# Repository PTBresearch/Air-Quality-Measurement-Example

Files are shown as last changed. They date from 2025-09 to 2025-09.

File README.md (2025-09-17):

# Note: This repository is meant as an example. The code is incomplete and not the latest version. 

# Note: The global InfluxDB instance is planned to be replaced by Fiware.

# Air Quality

## Sensors List (Not Complete)

+ **PPD42NS** (Dust Concentration)

+ **BME280** (Humidity, Air Pressure, Temperature)

+ **CCS811** (TVOC Value, CO2 Equivalent)

+ **MAX31855PMB1#** (Temperature)

+ **SHT35** (Temperature, Humidity)

+ **GUVA-S12D** (UV)

+ **TCS34725** Light Sensor (RGB, Color Temperature, Brightness, Reference Value)

+ **MH-Z19C** (CO2 Value Infrared Sensor, Temperature)

+ **SPH** (DB)

+ **HP206C** ()

## Images and Render

<table>
  <tr>
    <td>
      Front Image
      <figcaption>Blender Case with PCB Render</figcaption>
    </td>
    <td>
      Front Image
      <figcaption>Blender Base with PCB Render</figcaption>
    </td>
    <td>
      Front Image
      <figcaption>Blender PCB Render</figcaption>
    </td>
  </tr>
  <tr>
    <td>
      Front Image
      <figcaption>Full Top</figcaption>
    </td>
    <td>
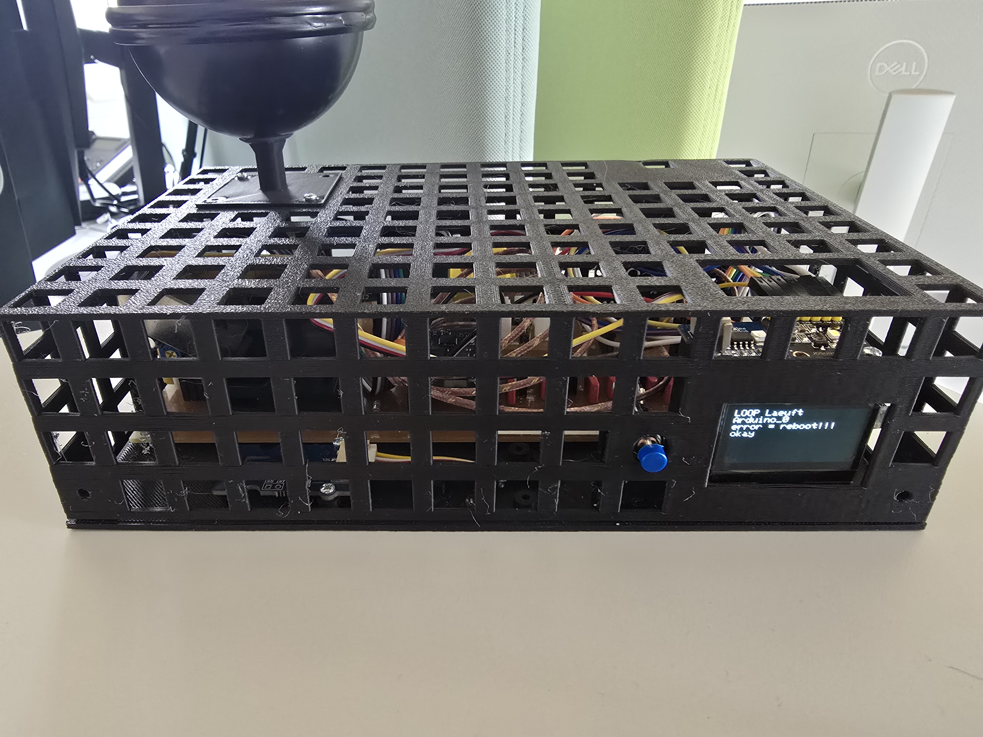
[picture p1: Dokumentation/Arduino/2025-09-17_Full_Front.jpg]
Front Image
      
      <figcaption>Full Front</figcaption>
    </td>
    <td>
      Front Image
      <figcaption>Sensor Station</figcaption>
    </td>
  </tr>
  <tr>
    <td>
      Side Image
      <figcaption>Open PCB V1</figcaption>
    </td>
    <td>
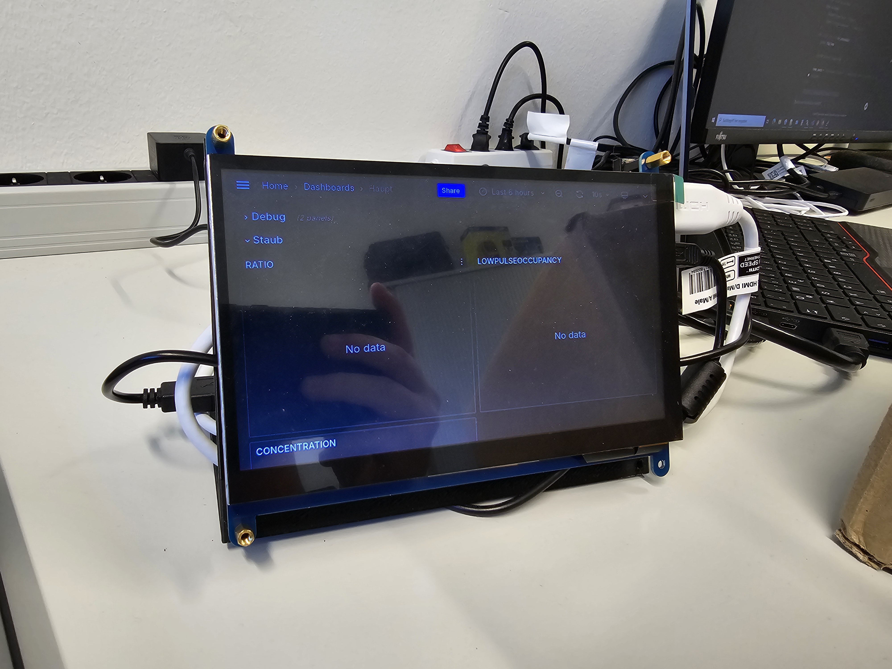
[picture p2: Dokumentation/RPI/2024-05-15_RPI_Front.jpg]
Front Image
      
      <figcaption>Front View</figcaption>
    </td>
    <td>
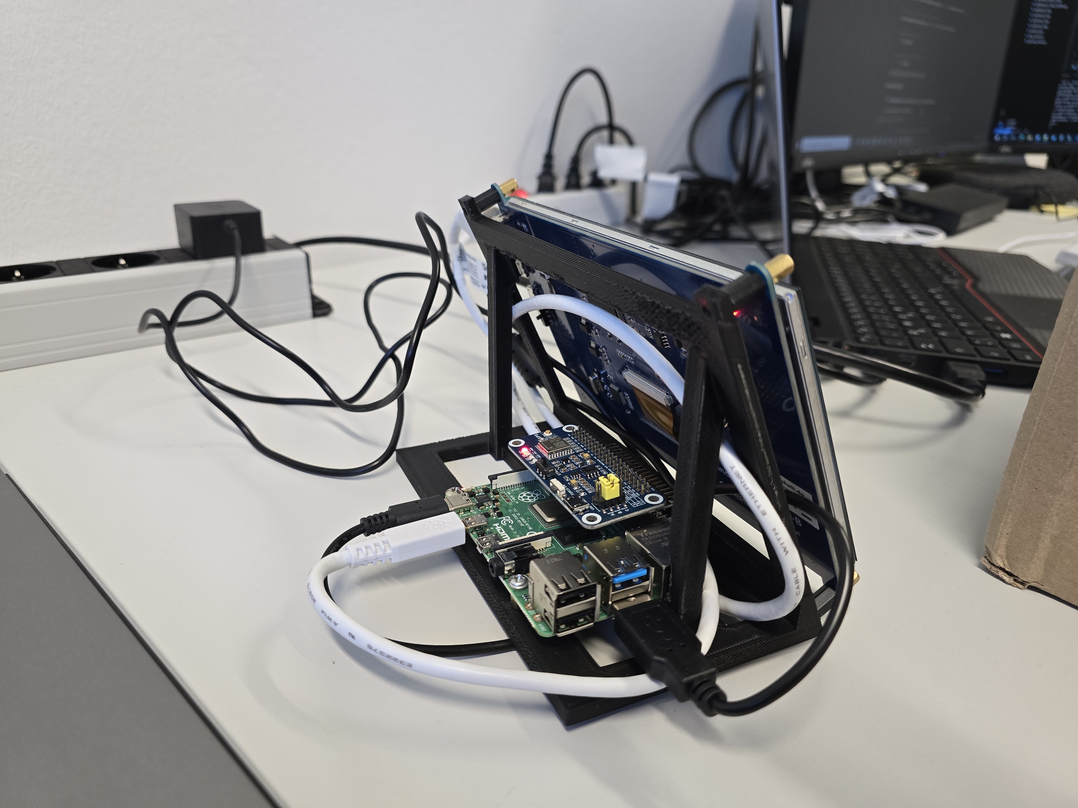
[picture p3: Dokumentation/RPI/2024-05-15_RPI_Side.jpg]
Side Image
      
      <figcaption>Side View</figcaption>
    </td>
  </tr>
</table>

## Structure

```
.
├── Arduino-Code/          # The main folder for all microcontroller code.
│   ├── Main/              # Code for the primary Arduino prototype (likely ESP8266).
│   │   ├── lib/           # Libraries for this specific project.
│   │   └── Main.ino # The main program file for the Arduino.
│
├── Dokumentation/         # Images.
│
├── Files/                 # Specific files relevant to hardware and measurements.
│   ├── Gehaeuse/          # 3D models and design files for the project's enclosure.
│   └── Platinen/          # Design files (Gerber files, etc.) for the printed circuit boards (PCBs).
│
└── Raspberry-Installer/   # Scripts and files for setting up the Raspberry Pi.
    └── Docker/            # Docker configurations and source code for installing services on the Pi.
        └── src/           # Source code used by the Docker containers.
```

## Function

```
┌── Raspberry Pi
│   └── Creates a Wi-Fi network
│
└── Arduino
    ├── Connects to the Wi-Fi network
    │
    ├── Reads data from the sensor
    │
    └── Sends data over Wi-Fi to the API
        │
        └── API
            ├── Collects the sent data
            │
            ├── Inserts the data into a local database (InfluxDB)
            │
            └── Inserts the data into a global database (InfluxDB)
```

## Example JSON-Structure

```
{
  "arduino_board": "<arduino_id>",
  "sensors": [
    {
      "name": "<sensor_name>",
      "sensor_model": "<sensor_model>",
      "readings": [
        {
          "type": "<influx measurement>",
          "value": VALUE,
          "unit": "<unit>"
          "label": "<label optional>"
        },
        {
          "type": "<influx measurement>",
          "value": VALUE,
          "unit": "<unit>"
          "label": "<label optional>"
        }
      ]
    },
    {
      "name": "bme280",
      "sensor_model": "",
      "readings": [
        {
          "type": "temperature",
          "value": VALUE,
          "unit": "celsius"
        },
        {
          "type": "pressure",
          "value": VALUE,
          "unit": "hpa"
        },
        {
          "type": "humidity",
          "value": VALUE,
          "unit": "%"
        }
      ]
    }
  ]
}
```

---

## Instalation

1. Download: 

```bash
git clone <url> luftqualitaet
```

2. Edit ```WLAN_SSID``` in ```luftqualitaet/Raspberry-Installer/config.sh``` 
```bash
export replace=<Hostname>
sed -i -e 's/WLAN_SSID = Hostname/WLAN_SSID = ${replace}/g' luftqualitaet/Raspberry-Installer/config.sh
```

3. (Optional) Set Proxy Settings ```luftqualitaet/Raspberry-Installer/Docker/.env```
```bash
echo "http_proxy=http://webproxy:8080
https_proxy=http://webproxy:8080
no_proxy=influx,localhost" > /home/pi/luftqualitaet/Raspberry-Installer/Docker/.env
```

4. Login as Root
```bash
sudo -i
```

5. Change directory to Installer Location
```bash
cd /home/pi/luftqualitaet/Raspberry-Installer
```

6. Make Script executeable
```bash
chmod +x config.sh setup.sh
```

7. Set Current Time
```bash
HTTP_DATE=$(curl -x http://webproxy:8080  -ksI 'https://ptb.de' | grep -i '^date:' | sed 's/Date: //i' | sed 's/ (GMT)//')
if [ -n "$HTTP_DATE" ]; then date -s "$HTTP_DATE" && echo "Systemzeit erfolgreich gesetzt."; else echo "WARNUNG: Konnte die Zeit nicht über HTTP abrufen."; fi
```

8. Run Script
```
./setup.sh
```

9. Change directory to Docker Location
```bash
cd /home/pi/luftqualitaet/Raspberry-Installer/Docker
```

10. Start Docker
```bash
docker compose up -d
```

11. Setup Influxdb (http://hostname:8086) and Grafan (http://hostname:3000) 

12. Set InfluxDB Token in Config ```/home/pi/Raspberry-Installer/Docker/src/config.yml````

13. Restart Docker
```bash
docker compose down
docker compose up -d
```

14. Restart Raspberry PI
```bash
systemctl reboot
```

---

## Components

### Raspberry PI

| Component | Order Link | Datasheet Link(s) | Further Information |
|---|---|---|---|
| Pi 4B | [https://www.reichelt.de/das-reichelt-raspberry-pi-4-b-4-gb-all-in-bundle-rpi-4b-4gb-allin-p263086.html](https://www.reichelt.de/das-reichelt-raspberry-pi-4-b-4-gb-all-in-bundle-rpi-4b-4gb-allin-p263086.html) | | |
| Micro SD | [https://www.reichelt.de/de/de/shop/produkt/microsdxc-speicherkarte_128gb_samsung_pro_plus-313955](https://www.reichelt.de/de/de/shop/produkt/microsdxc-speicherkarte_128gb_samsung_pro_plus-313955) | | |
| GPS | [https://www.reichelt.de/de/de/shop/produkt/raspberry_pi_shield_-_multi-gnss_l76x-266060](https://www.reichelt.de/de/de/shop/produkt/raspberry_pi_shield_-_multi-gnss_l76x-266060) | | |
| Raspberry Pi Shield | [https://www.reichelt.de/de/de/shop/produkt/raspberry_pi_shield_-_display_lcd-touch_7_800x480_pixel-282508](https://www.reichelt.de/de/de/shop/produkt/raspberry_pi_shield_-_display_lcd-touch_7_800x480_pixel-282508) | | |

### Sensor Station

| Component | Sensor Type | Order Link | Datasheet Link(s) | Notes | Ambient Temperature | Humidity | Air Pressure |
|---|---|---|---|---|---|---|---|
| **BME280** | Temp & Pressure Sensor | [https://www.reichelt.de/ch/de/shop/produkt/entwicklerboards\_-\_temperatur-\_feuchtigkeits-*und\_drucksensor*-253982](https://www.reichelt.de/ch/de/shop/produkt/entwicklerboards_-_temperatur-_feuchtigkeits-_und_drucksensor_-253982) | [https://cdn-reichelt.de/documents/datenblatt/A300/BST-BME280-DS002-1509607.pdf](https://cdn-reichelt.de/documents/datenblatt/A300/BST-BME280-DS002-1509607.pdf) | Inaccurate temperature (error tolerance of +3°C) | Accuracy: +1.0°C \<br\> Range: -40°C to +85°C \<br\> Max Deviation: Up to +1.5°C | Accuracy: +3% rF \<br\> Range: 0% to 100% rF \<br\> Max Deviation: up to +5% | Accuracy: +1 hPa \<br\> Range: 300 hPa \<br\> Max Deviation: Up to +1.7 hPa |
| **CCS811** | TVOC | [https://www.reichelt.de/ch/de/shop/produkt/entwicklerboards\_-\_sensor\_fuer\_luftqualitaet\_ccs811-253655](https://www.reichelt.de/ch/de/shop/produkt/entwicklerboards_-_sensor_fuer_luftqualitaet_ccs811-253655) | [https://cdn-reichelt.de/documents/datenblatt/A300/SEN-CCS811V1-DATENBLATT-02-11-2020.pdf](https://cdn-reichelt.de/documents/datenblatt/A300/SEN-CCS811V1-DATENBLATT-02-11-2020.pdf) | Has a burn-in period (48 hours) and a warm-up time (20 min) before it becomes accurate | Accuracy: +3°C \<br\> Range: 0°C to +50°C \<br\> Max Deviation: approx. +5°C | Range: 10% to 95% | |
| **PPD42NS** | Dust | [https://www.reichelt.de/ch/de/shop/produkt/arduino\_-\_staubsensor\_ppd42ns-191264](https://www.reichelt.de/ch/de/shop/produkt/arduino_-_staubsensor_ppd42ns-191264) | [https://cdn-reichelt.de/documents/datenblatt/A300/101020012\_01.pdf](https://cdn-reichelt.de/documents/datenblatt/A300/101020012_01.pdf) | Must be straight, requires 3 min to warm up, arbitrary operation can lead to damage, standard settings should not be changed | Recommended Range: -10°C to +65°C | Range: 0% to 70% | |
| **MAX31855PMB1\#** | Typk Temp | [https://de.farnell.com/analog-devices/max31855pmb1/peripheriemodul-thermoel-digit/dp/2530496](https://de.farnell.com/analog-devices/max31855pmb1/peripheriemodul-thermoel-digit/dp/2530496) | [https://www.farnell.com/datasheets/2025616.pdf](https://www.farnell.com/datasheets/2025616.pdf) | Inaccurate temperature (error tolerance of +2°C) | Recommended Range: -20°C to +85°C | Range: 0% to 95% | |
| **D1 Mini** | D1 Mini | [https://www.reichelt.de/de/de/shop/produkt/d1\_mini\_-\_kompatibles\_esp8266\_board\_v2\_0-253978](https://www.reichelt.de/de/de/shop/produkt/d1_mini_-_kompatibles_esp8266_board_v2_0-253978) | | | | | |
| **D1 Mini** | D1 Mini Pro | https:www.reichelt.de/de/de/shop/produkt/d1\_mini\_pro\_-\_kompatibles\_esp8266\_board\_cp2104-266066 | | | | | |
| **Power Supply** | Breadboard | [https://www.reichelt.de/de/de/shop/produkt/entwicklerboards\_-\_spannungsversorgung\_f\_steckboards-202832](https://www.reichelt.de/de/de/shop/produkt/entwicklerboards_-_spannungsversorgung_f_steckboards-202832) | [https://cdn-reichelt.de/documents/datenblatt/A300/DATENBLATTSBC-POW-BB.pdf](https://cdn-reichelt.de/documents/datenblatt/A300/DATENBLATTSBC-POW-BB.pdf) | Too high voltage can damage the device or even lead to a fire | Recommended Range: 0°C to +70°C | Range: 10% to 60% (Absolutely not intended for humid rooms) | |
| **GSM18E09-P1J** | Plug-in Power Supply | [https://www.conrad.de/de/p/mean-well-gsm18e09-p1j-steckernetzteil-festspannung-9-v-dc-2-a-18-w-1837961.html](https://www.conrad.de/de/p/mean-well-gsm18e09-p1j-steckernetzteil-festspannung-9-v-dc-2-a-18-w-1837961.html) | [https://asset.conrad.com/media10/add/160267/c1/-/en/001837961DS01/datenblatt-1837961-mean-well-gsm18e09-p1j-steckernetzteil-festspannung-9-vdc-2-a-18-w.pdf](https://asset.conrad.com/media10/add/160267/c1/-/en/001837961DS01/datenblatt-1837961-mean-well-gsm18e09-p1j-steckernetzteil-festspannung-9-vdc-2-a-18-w.pdf) | Only lasts 3 years and is only 88% efficient | Recommended Range: -25 to +60 | Range: 20% to 90% | |
| **SHT35** | Temp & Humidity | [https://de.farnell.com/seeed-studio/101020212/sensorplatine-arduino-board/dp/3932104](https://de.farnell.com/seeed-studio/101020212/sensorplatine-arduino-board/dp/3932104) | [https://www.farnell.com/datasheets/3708357.pdf](https://www.farnell.com/datasheets/3708357.pdf) | Environmentally sensitive and should not be touched with fingers as it can be damaged | Recommended Range: -40°C to 125°C | Range: 10% to 90% | |
| **ADC** | Analog Digital Converter | [https://www.conrad.de/de/p/joy-it-ky053adc-raspberry-pi-erweiterungs-platine-passend-fuer-einplatinen-computer-raspberry-pi-raspberry-pi-a-b-1656368.html](https://www.conrad.de/de/p/joy-it-ky053adc-raspberry-pi-erweiterungs-platine-passend-fuer-einplatinen-computer-raspberry-pi-raspberry-pi-a-b-1656368.html) | [https://asset.conrad.com/media10/add/160267/c1/-/de/001656368DS01/datenblatt-1656368-joy-it-ky053adc-raspberry-pi-erweiterungs-platine-passend-fuer-einplatinen-compu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](https://asset.conrad.com/media10/add/160267/c1/-/de/001656368DS01/datenblatt-1656368-joy-it-ky053adc-raspberry-pi-erweiterungs-platine-passend-fuer-einplatinen-compu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) | Sensitive to interference due to its high resolution, which can make it slower to measure rapidly changing signals or values | Recommended Range: -40°C to 125°C | Range: 0% to 95% | |
| **GUVA-S12D** | UV Sensor | [https://www.reichelt.de/de/de/shop/produkt/arduino\_-\_uv-sensor\_guva-s12d-191215](https://www.reichelt.de/de/de/shop/produkt/arduino_-_uv-sensor_guva-s12d-191215) | [https://cdn-reichelt.de/documents/datenblatt/A300/101020043\_01.pdf](https://cdn-reichelt.de/documents/datenblatt/A300/101020043_01.pdf) | Can be altered by temperature, sensitive to environmental influences, not precise | Recommended Range: -30°C to +85°C | Range: 0% to 95% | |
| **TCS34725** | Light Sensor | [https://www.conrad.de/de/p/az-delivery-tcs34725-rgb-farb-sensor-mit-infrarot-filter-diy-modul-zur-farb-erkennung-kompatibel-mit-arduino-850037694.html](https://www.conrad.de/de/p/az-delivery-tcs34725-rgb-farb-sensor-mit-infrarot-filter-diy-modul-zur-farb-erkennung-kompatibel-mit-arduino-850037694.html) | [https://ams-osram.com/products/sensor-solutions/ambient-light-color-spectral-proximity-sensors/ams-tcs34725-color-sensor](https://ams-osram.com/products/sensor-solutions/ambient-light-color-spectral-proximity-sensors/ams-tcs34725-color-sensor) | Light can change measurement values, the sensor has a certain amount of background noise | Recommended Range: -40°C to +85°C | Range: 0% to 60% | |
| **MH-Z19C** | CO2 Sensor | [https://www.reichelt.de/de/de/shop/produkt/infrarot\_co2-sensor\_mh-z19c\_pinleiste\_rm\_2\_54-297320](https://www.reichelt.de/de/de/shop/produkt/infrarot_co2-sensor_mh-z19c_pinleiste_rm_2_54-297320) | [https://cdn-reichelt.de/documents/datenblatt/C150/MH-Z19CDATENBLATT.pdf](https://cdn-reichelt.de/documents/datenblatt/C150/MH-Z19CDATENBLATT.pdf) | Only works at optimal temperatures (-10 \~ 50 °C) and is sensitive to heat and sun | Recommended Range: -10°C to 50°C | Range: 0% to 95% | |
| **Teensy4.1** | Teensy4.1 | [https://www.reichelt.de/de/de/shop/produkt/teensy\_4\_1\_usb\_ohne\_header-283580](https://www.reichelt.de/de/de/shop/produkt/teensy_4_1_usb_ohne_header-283580) | [https://cdn-reichelt.de/documents/datenblatt/A300/TEENSY\_41\_DE.pdf](https://cdn-reichelt.de/documents/datenblatt/A300/TEENSY_41_DE.pdf) | Consumes a lot of power, lacks a Wi-Fi or Bluetooth connection, and can overheat during complex tasks | Recommended Range: -40°C to +85°C | Range: 0% to 95% | |
| **HP206C** | Grove - Barometer | [https://de.farnell.com/seeed-studio/101020068/sensor-barometer-arduino-raspberry/dp/4007687](https://de.farnell.com/seeed-studio/101020068/sensor-barometer-arduino-raspberry/dp/4007687) | [https://www.farnell.com/datasheets/3759062.pdf](https://www.farnell.com/datasheets/3759062.pdf) | The chip only accepts an input voltage of 1.8 V to 3.6 V. | Recommended Range: -40°C to +85°C | Range: 5% to 90% | |

### Mic

| Component | Sensor Type | Order Link | Datasheet Link(s) | Notes | Ambient Temperature | Humidity | Air Pressure |
|---|---|---|---|---|---|---|---|
| SPH0645 | Mems Mic | [https://www.reichelt.de/de/de/shop/produkt/entwicklerboards_-_mikrofone_sph0645-271874](https://www.reichelt.de/de/de/shop/produkt/entwicklerboards_-_mikrofone_sph0645-271874) | [https://cdn-reichelt.de/documents/datenblatt/A300/DEBO_MEMS_MIC_DB_EN.pdf](https://cdn-reichelt.de/documents/datenblatt/A300/DEBO_MEMS_MIC_DB_EN.pdf) | Sensitive to air, especially at the porthole (may require further investigation later) | Recommended Range: -40°C to +85°C | Range: 5% to 95% | |
| D1 Mini | D1 Mini | [https://www.reichelt.de/de/de/shop/produkt/d1_mini_-_kompatibles_esp8266_board_v2_0-253978](https://www.reichelt.de/de/de/shop/produkt/d1_mini_-_kompatibles_esp8266_board_v2_0-253978) | | | | | |
| D1 Mini | D1 Mini Pro | https:www.reichelt.de/de/de/shop/produkt/d1_mini_pro_-_kompatibles_esp8266_board_cp2104-266066 | | | | | |
| D1 Mini | D1 Mini Lite | [https://www.reichelt.de/de/de/shop/produkt/d1_mini_lite_-_kompatibles_esp8285_board-291438](https://www.reichelt.de/de/de/shop/produkt/d1_mini_lite_-_kompatibles_esp8285_board-291438) | | | | | |
| Teensy4.1 | Teensy4.1 | [https://www.reichelt.de/de/de/shop/produkt/teensy_4_1_usb_ohne_header-283580](https://www.reichelt.de/de/de/shop/produkt/teensy_4_1_usb_ohne_header-283580) | [https://cdn-reichelt.de/documents/datenblatt/A300/TEENSY_41_DE.pdf](https://cdn-reichelt.de/documents/datenblatt/A300/TEENSY_41_DE.pdf) | Consumes a lot of power, lacks a Wi-Fi or Bluetooth connection, and can overheat during complex tasks | Recommended Range: -40°C to +85°C | Range: 0% to 95% | |
| Power Supply | USB Charger | [https://www.reichelt.de/de/de/shop/produkt/usb-ladegeraet_5_v_1_a_usb-c_schwarz-268087?PROVID=2788](https://www.reichelt.de/de/de/shop/produkt/usb-ladegeraet_5_v_1_a_usb-c_schwarz-268087?PROVID=2788) | | | | | |

---

## Notes on Individual Sensors (Regarding Placement)

+ **BME280 Temperature, Air Pressure, Humidity Sensor:**
    + [https://www.makershop.de/download/bst-bme280-ds002.pdf](https://www.makershop.de/download/bst-bme280-ds002.pdf)
    + Do not place near heaters.

+ **CCS811 Carbon Dioxide Gas Sensor Metal Oxide:**
    + [https://www.makershop.de/download/CCS811_Datasheet-DS000459.pdf](https://www.makershop.de/download/CCS811_Datasheet-DS000459.pdf)
    + No special measures required.

+ **TCS3472 Color Sensor:**
    + [https://cdn.shopify.com/s/files/1/1509/1638/files/TCS3472_datasheet_1692bf77-3213-4bd2-9a66-8a9e70545e7e.pdf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](https://cdn.shopify.com/s/files/1/1509/1638/files/TCS3472_datasheet_1692bf77-3213-4bd2-9a66-8a9e70545e7e.pdf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)
    + The sensor should have access to light.
    + Not next to an LED on the ESP microcontroller.

+ **GRV Loudness Sensor:**
    + [https://cdn-reichelt.de/documents/datenblatt/A300/101020063_01.pdf](https://cdn-reichelt.de/documents/datenblatt/A300/101020063_01.pdf)
    + The sensor should have external access.
    + Should be able to capture ambient sound.
    + Do not place it behind a cover.

+ **GRV Dust Sensor:**
    + [https://cdn-reichelt.de/documents/datenblatt/A300/101020012_01.pdf](https://cdn-reichelt.de/documents/datenblatt/A300/101020012_01.pdf)
    + The chip on the back gets hot occasionally.
    + Has a built-in fan, so do not place it directly next to the GRV Loudness sensor.

---

## General Notes

+ The enclosure must be sufficiently open to allow air to flow in for measurements.
+ Ensure thermal, optical, and acoustic decoupling of the microcontroller from the sensors (use a partition).
+ Leave space for 2-3 additional sensors (check sensor dimensions with a reference image).
+ Leave space for 2 more ESPs (D1 Mini Lite), for a total of 3.

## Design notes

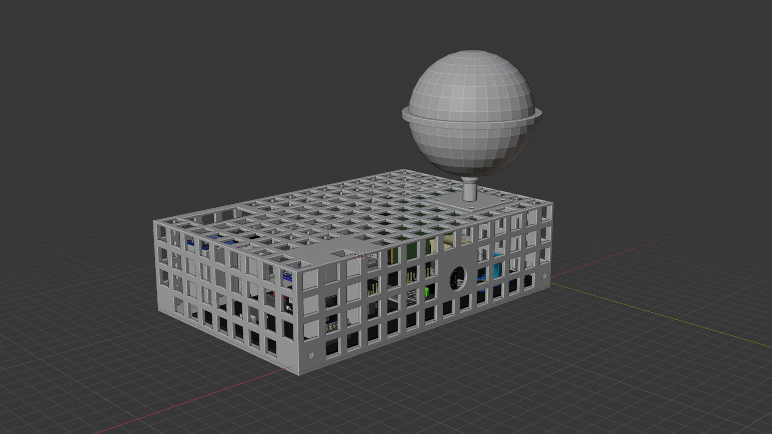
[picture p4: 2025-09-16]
Dokumentation/Arduino/2025-09-16-PCB-V3-Blender-Render-Case.png

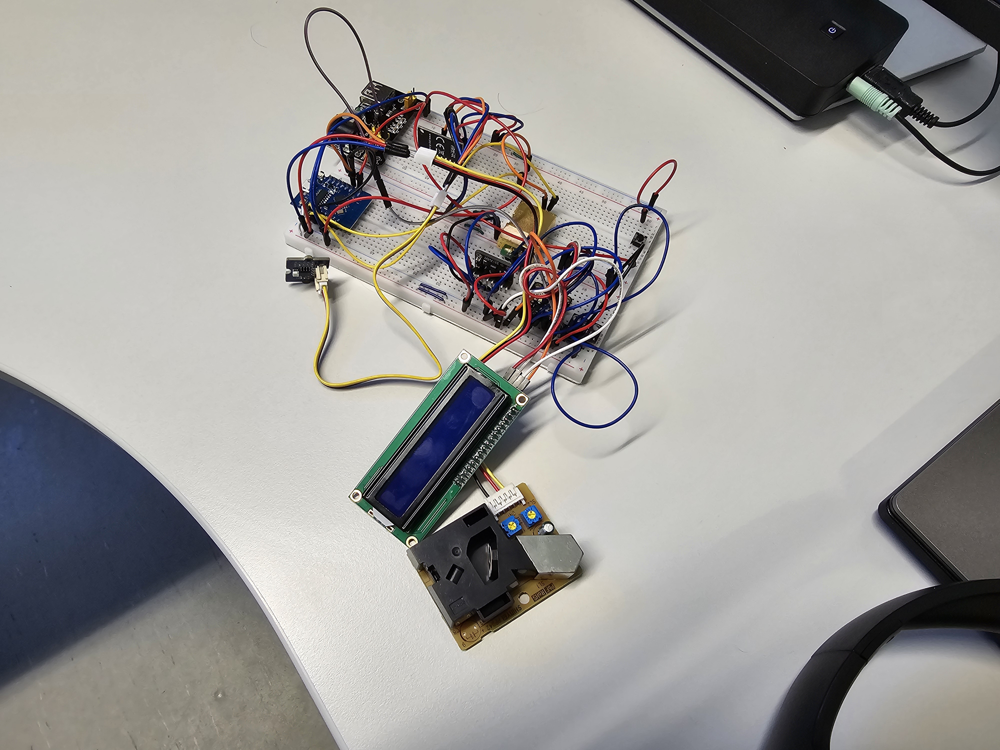
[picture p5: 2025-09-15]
Dokumentation/Arduino/2024-05-15_Breadboard_V2_Other_angle.jpg

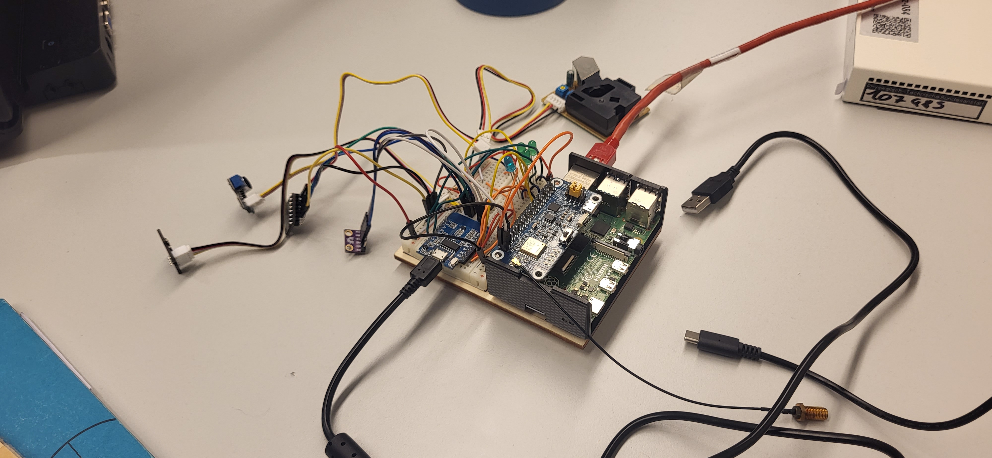
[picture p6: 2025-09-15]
Dokumentation/Arduino/2023-11-20_Breadboard_V1_Left.jpg

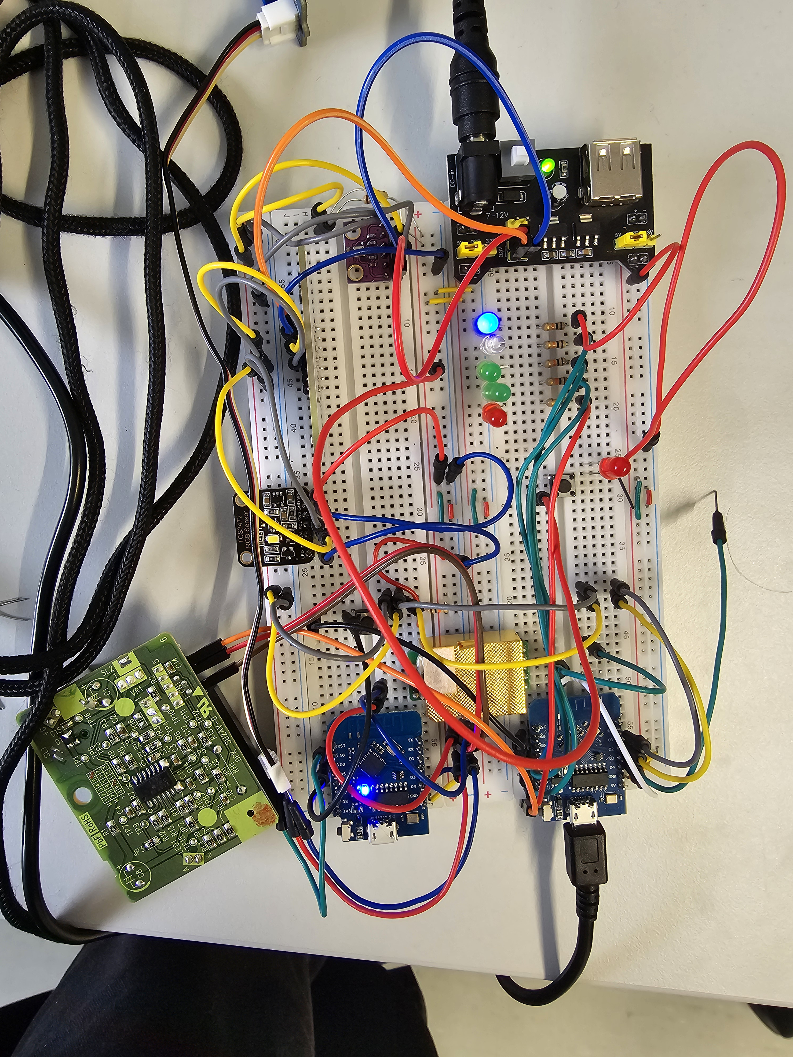
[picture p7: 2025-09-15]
Dokumentation/Arduino/2024-03-13_Breadboard_V2_Top.jpg

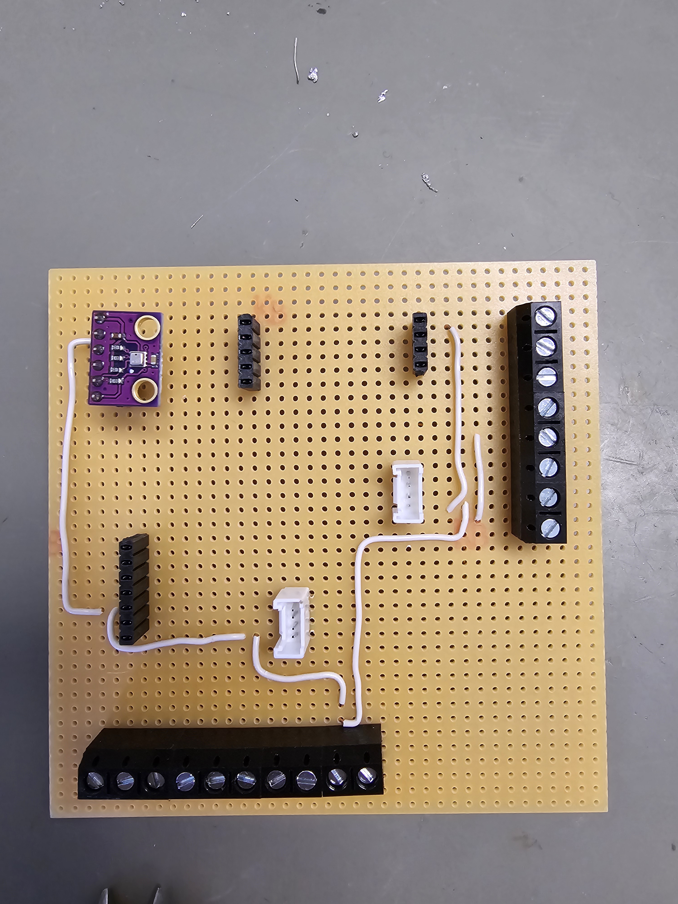
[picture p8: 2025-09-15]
Dokumentation/Arduino/2024-04-04_Circut_Board_Idea_Connectors.jpg

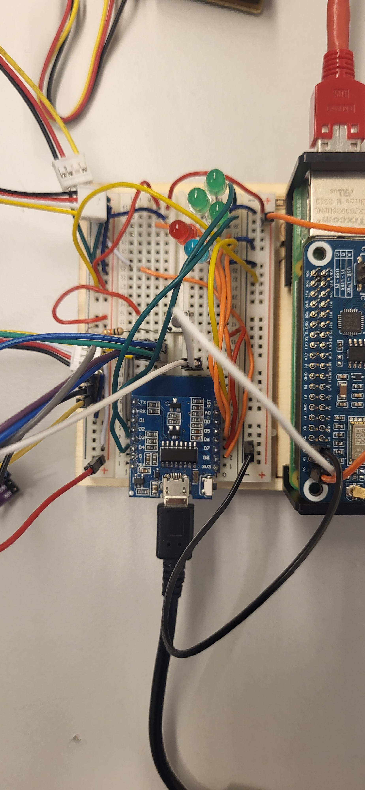
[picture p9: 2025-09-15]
Dokumentation/Arduino/2023-11-20_Breadboard_V1_Top.jpg

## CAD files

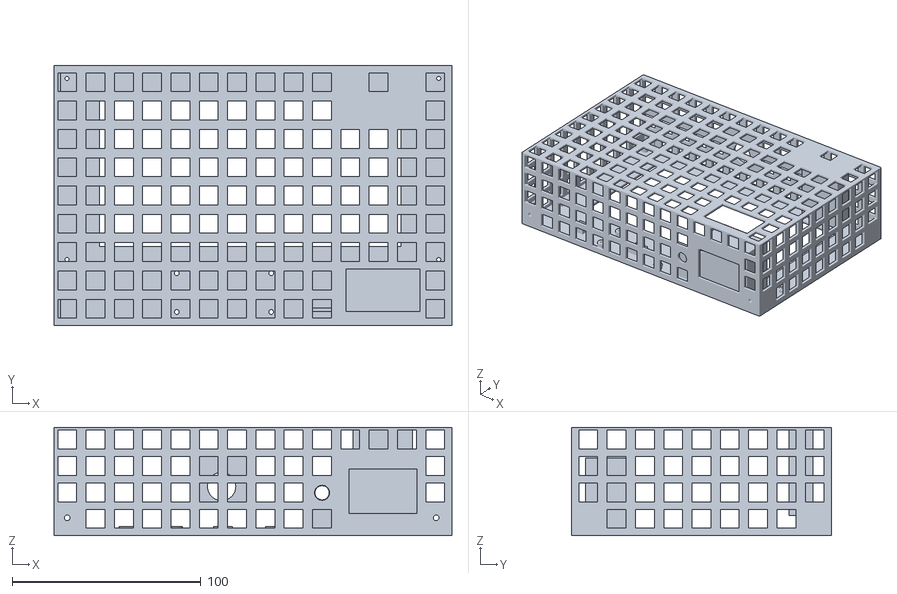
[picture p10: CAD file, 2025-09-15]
Files/Gehaeuse/Gehäuse.stl
210.9 x 138.0 x 57.5

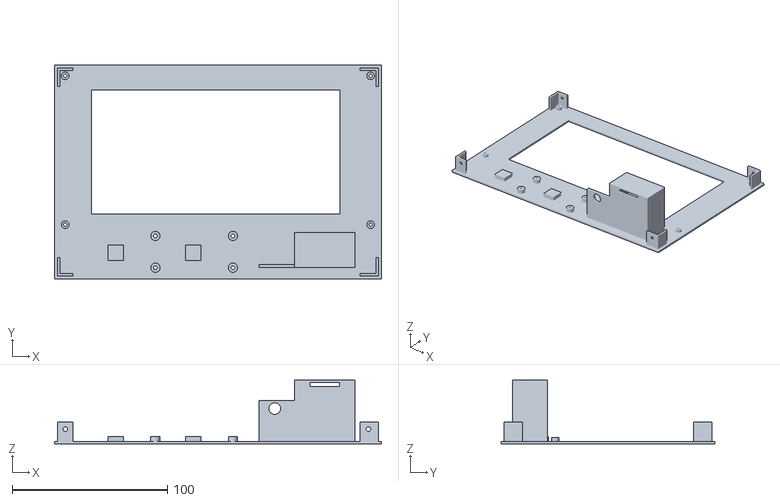
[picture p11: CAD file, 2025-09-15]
Files/Gehaeuse/Gehäuse-Boden.stl
210.9 x 138.0 x 41.1

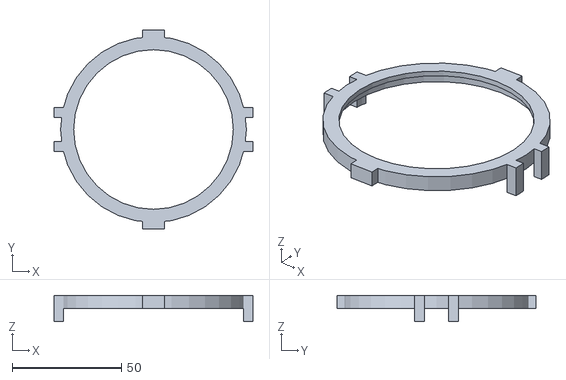
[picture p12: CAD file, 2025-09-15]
Files/Gehaeuse/Kugel-Halter.stl
91.0 x 91.0 x 12.0

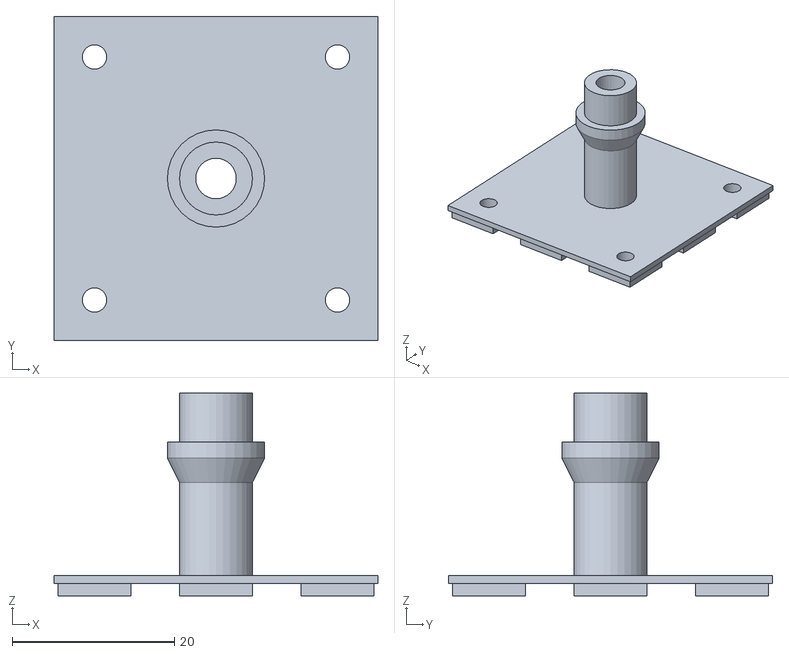
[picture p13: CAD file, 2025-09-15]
Files/Gehaeuse/Gehäuse-Globe.stl
40.0 x 40.0 x 25.0

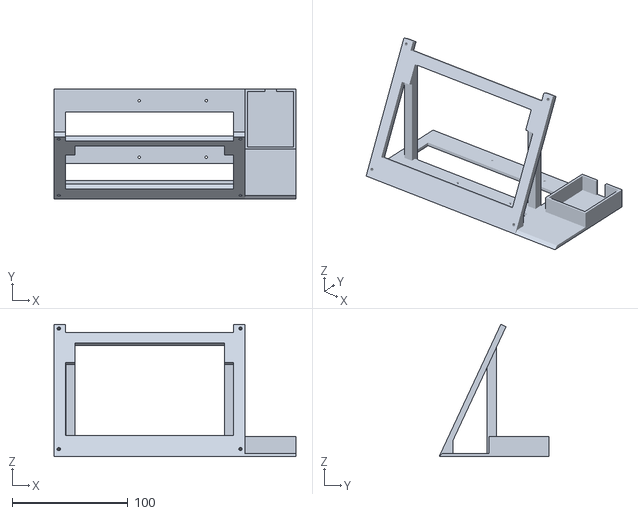
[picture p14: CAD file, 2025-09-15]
Files/Gehaeuse/Bildschirm.stl
209.1 x 95.0 x 114.5

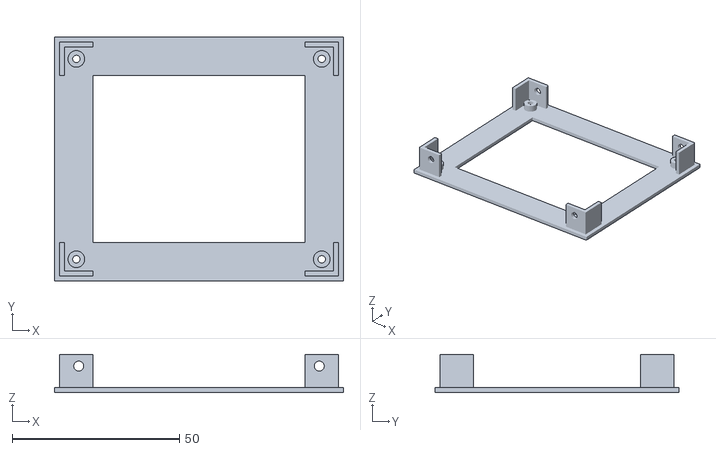
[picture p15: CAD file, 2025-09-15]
Files/Gehaeuse/Mikrofon-Boden.stl
86.5 x 73.0 x 11.5

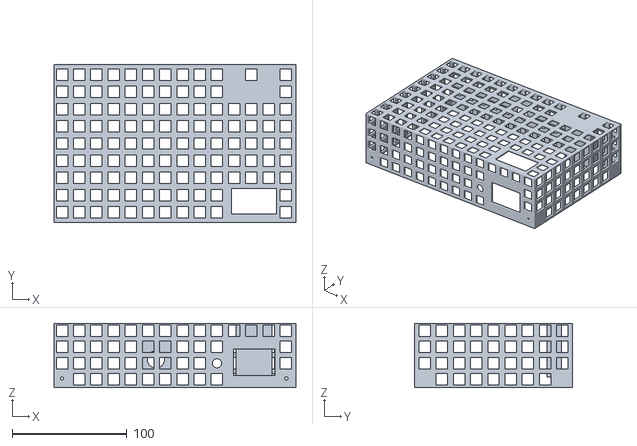
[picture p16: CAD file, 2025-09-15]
Files/Gehaeuse/Gehäuse-Deckel.stl
210.9 x 138.0 x 55.9

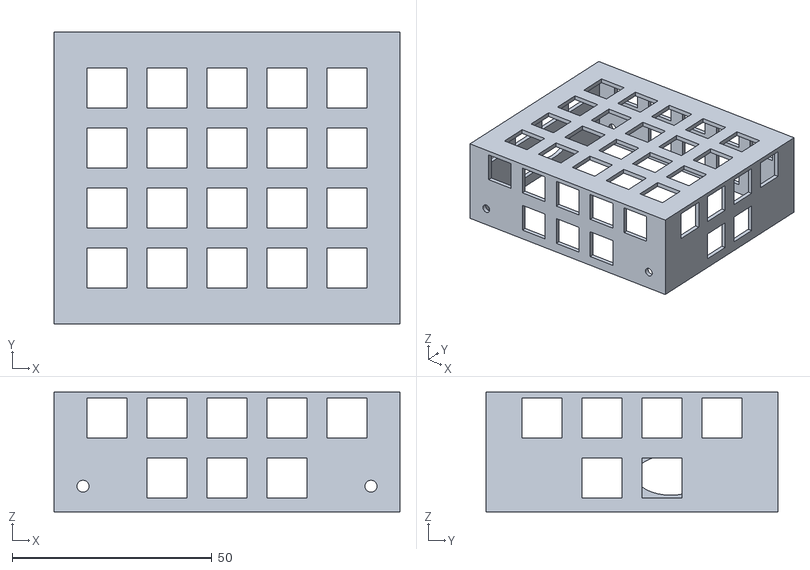
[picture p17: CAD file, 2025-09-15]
Files/Gehaeuse/Mikrofon-Deckel.stl
86.5 x 73.0 x 30.0

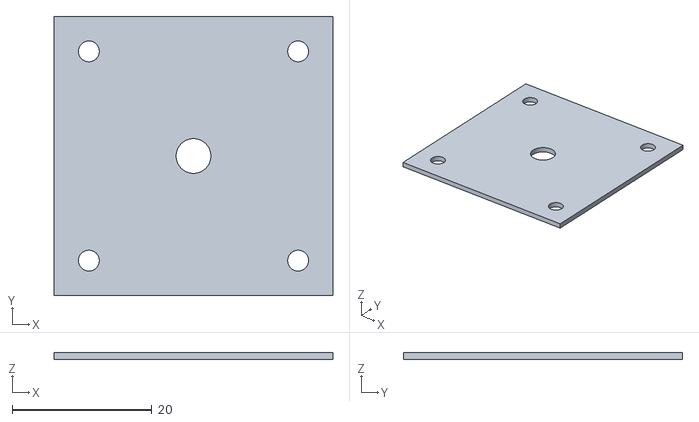
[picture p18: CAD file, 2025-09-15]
Files/Gehaeuse/Gehäuse-Globe-Boden.stl
40.0 x 40.0 x 1.00

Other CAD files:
Files/Gehaeuse/Bildschirm.blend
Files/Gehaeuse/Gehäuse.blend
Files/Gehaeuse/Mikrofon.blend

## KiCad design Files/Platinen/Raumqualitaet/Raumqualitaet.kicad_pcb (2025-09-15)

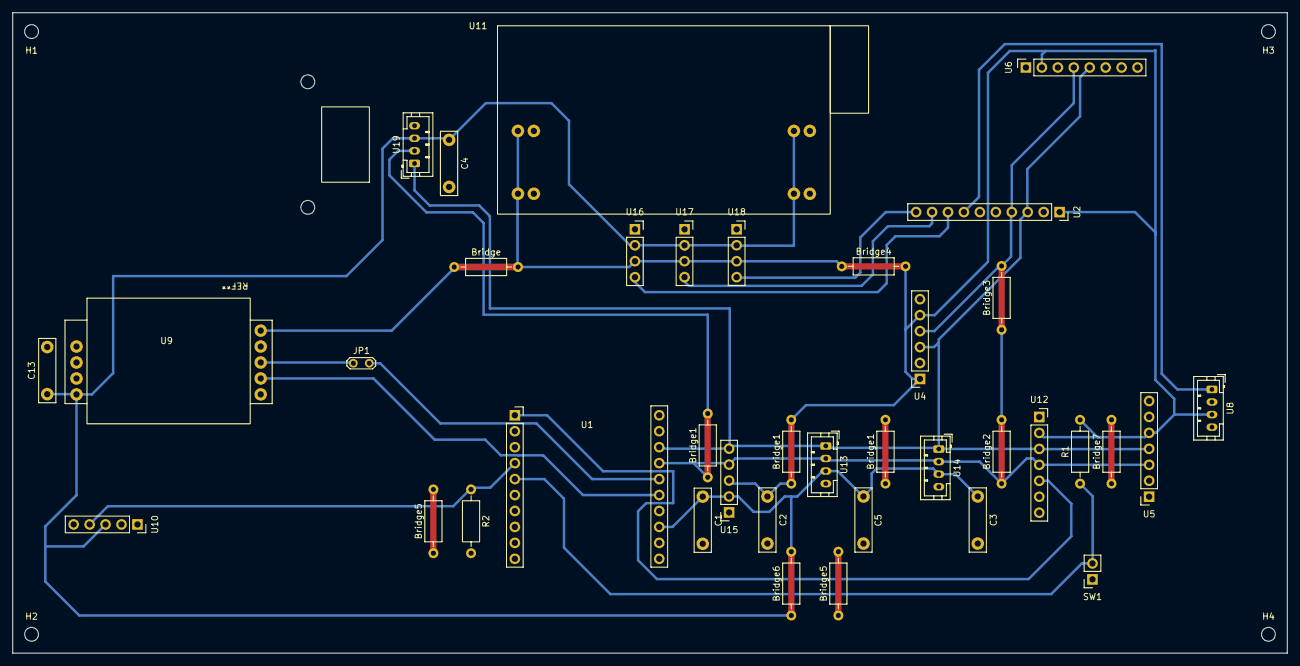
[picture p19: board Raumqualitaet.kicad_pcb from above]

Board: 2 copper layers, 203.0 x 102.0 mm, 42 parts (0 on the bottom side), 15 nets.

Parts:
Bridge: Bridge; R_Axial_DIN0207_L6.3mm_D2.5mm_P10.16mm_Horizontal
Bridge1, Bridge1#2, Bridge1#3: Bridge:1; R_Axial_DIN0207_L6.3mm_D2.5mm_P10.16mm_Horizontal
Bridge2: Bridge2; R_Axial_DIN0207_L6.3mm_D2.5mm_P10.16mm_Horizontal
Bridge3: Bridge3; R_Axial_DIN0207_L6.3mm_D2.5mm_P10.16mm_Horizontal
Bridge4: Bridge4; R_Axial_DIN0207_L6.3mm_D2.5mm_P10.16mm_Horizontal
Bridge5, Bridge5#2: Bridge5; R_Axial_DIN0207_L6.3mm_D2.5mm_P10.16mm_Horizontal
Bridge6: Bridge6; R_Axial_DIN0207_L6.3mm_D2.5mm_P10.16mm_Horizontal
Bridge7: Bridge7; R_Axial_DIN0207_L6.3mm_D2.5mm_P10.16mm_Horizontal
C1, C2, C3, C4, C5, C13: 100n; C_Rect_L10.0mm_W2.5mm_P7.50mm_MKS4
H1, H2, H3, H4: MountingHole; MountingHole_2.2mm_M2_DIN965
JP1: Jumper_2_Bridged; Jumper_2.54mm
R1: 10k; R_Axial_DIN0207_L6.3mm_D2.5mm_P10.16mm_Horizontal
R2: R; R_Axial_DIN0207_L6.3mm_D2.5mm_P10.16mm_Horizontal
SW1: SW_Push; PinSocket_1x02_P2.54mm_Vertical
U1: WeMos_D1_mini; ESP32_D1
U2: KY053ADC; PinSocket_1x10_P2.54mm_Vertical
U4: BMP280; PinSocket_1x06_P2.54mm_Vertical
U5: TCS3472; PinSocket_1x07_P2.54mm_Vertical
U6: SEN-CCS811; PinSocket_1x08_P2.54mm_Vertical
U8: UV - Pin 1 as Data; JST_PH_B4B-PH-K_1x04_P2.00mm_Vertical
U9: MH-Z19C
U10: PPD42; PinSocket_1x05_P2.54mm_Vertical
U11: SBC-POW-BB
U12: Display; PinSocket_1x07_P2.54mm_Vertical
U13, U14, U19: Grove Device; JST_PH_B4B-PH-K_1x04_P2.00mm_Vertical
U15: I2C_Device; PinSocket_1x05_P2.54mm_Vertical
U16, U17, U18: Analog_Device; PinSocket_1x04_P2.54mm_Vertical

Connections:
+3V3: Bridge.1, Bridge.2, Bridge1#3.1, Bridge1#3.2, Bridge4.1, Bridge4.2, C2.1, R1.2, U2.1 (VCC), U4.1 (VCC), U4.5 (CSB), U5.5 (3V3), U6.2 (3V3), U8.3 (5V), U9.9 (HD), U11.1 (3V3), U11.2 (3V3), U12.2 (3V3), U15.3 (3V3), U16.3 (3V3), U17.3 (3V3), U18.3 (3V3)
+5V: Bridge6.1, Bridge6.2, C1.1, C3.1, C4.1, C5.1, C13.1, U1.9 (5V), U9.4 (VCC), U10.3 (VCC), U11.5 (5V), U11.6 (5V), U13.3 (5V), U14.3 (5V), U15.2 (5V), U16.2 (5V), U17.2 (5V), U18.2 (5V), U19.3 (5V)
A0: U2.7 (A0), U8.1 (Analog)
A1: U2.8 (A1), U16.4 (Signal)
A2: U2.9 (A2), U17.4 (Signal)
A3: U2.10 (A3), U18.4 (Signal)
D3: JP1.2 (B), U1.12 (D3)
D4: U1.11 (D4), U9.6 (Rx)
D5: R2.1, U1.4 (SCK/D5), U10.4 (Output_(P1))
D6: R1.1, SW1.2, U1.5 (MISO/D6)
GND: Bridge1.1, Bridge1.2, Bridge5.1, Bridge5.2, Bridge5#2.1, Bridge5#2.2, Bridge7.1, Bridge7.2, C1.2, C2.2, C3.2, C4.2, C5.2, C13.2, R2.2, SW1.1, U1.10 (GND), U2.2 (GND), U4.2 (GND), U4.6 (SDO), U5.1 (LED), U5.6 (GND), U6.3 (GND), U6.6 (WAKE), U8.4 (GND), U9.3 (GND), U10.1 (GND), U11.3 (GND), U11.4 (GND), U11.7 (GND), U11.8 (GND), U12.1 (GND), U12.6 (Dc), U12.7 (Cs), U13.4 (GND), U14.4 (GND), U15.1 (GND), U16.1 (GND), U17.1 (GND), U18.1 (GND), U19.4 (GND)
unnamed: JP1.1 (A), U9.7 (Tx)
RST: U1.1 (~RST), U12.5 (RES)
SCL: U1.14 (SCL/D1), U2.3 (SCL), U4.3 (SCL), U5.4 (SCL), U6.5 (SCL), U12.3 (SCL), U13.1 (SCL), U14.1 (SCL), U15.5 (SCL), U19.1 (SCL)
SDA: Bridge1#2.1, Bridge1#2.2, Bridge2.1, Bridge2.2, Bridge3.1, Bridge3.2, U1.13 (SDA/D2), U2.4 (SDA), U4.4 (SDA), U5.3 (SDA), U6.4 (SDA), U12.4 (SDA), U13.2 (SDA), U14.2 (SDA), U15.4 (SDA), U19.2 (SDA)

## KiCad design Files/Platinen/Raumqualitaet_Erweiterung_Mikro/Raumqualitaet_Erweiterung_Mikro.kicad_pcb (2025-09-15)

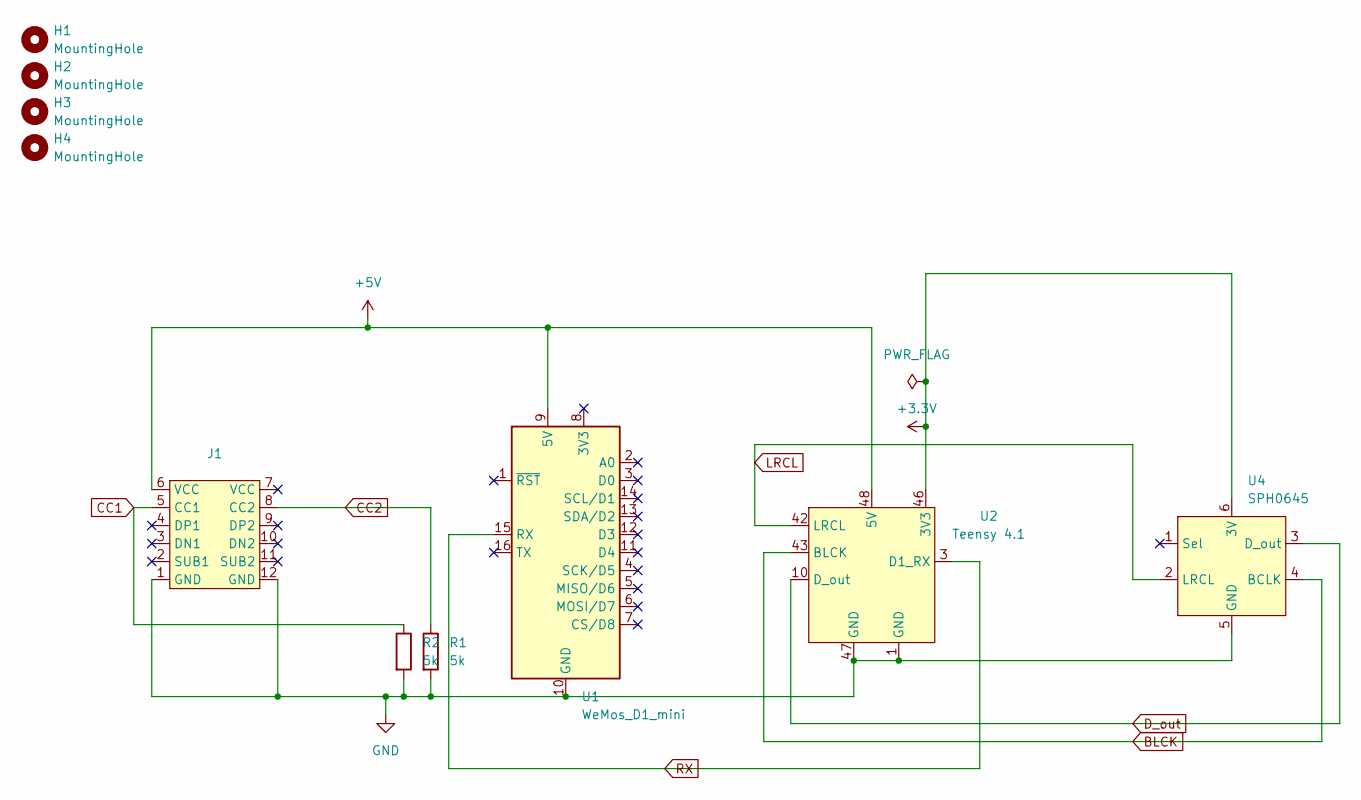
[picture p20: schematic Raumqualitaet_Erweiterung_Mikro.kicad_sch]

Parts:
H1, H2, H3, H4: MountingHole; MountingHole_2.2mm_M2_DIN965
J1: USB-C-DR-YM-726
R1, R2: 5k; R_Axial_DIN0207_L6.3mm_D2.5mm_P10.16mm_Horizontal
U1: WeMos_D1_mini; WEMOS_D1_mini_light
U2: Teensy 4.1; Teensy
U4: SPH0645; PinSocket_1x06_P2.54mm_Vertical

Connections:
+3.3V: U2.46 (3V3), U4.6 (3V)
+5V: J1.6 (VCC), U1.9 (5V), U2.48 (5V)
BLCK: U2.43 (BLCK), U4.4 (BCLK)
CC1: J1.5 (CC1), R2.1
CC2: J1.8 (CC2), R1.1
D_out: U2.10 (D_out), U4.3 (D_out)
GND: J1.1 (GND), J1.12 (GND), R1.2, R2.2, U1.10 (GND), U2.1 (GND), U2.47 (GND), U4.5 (GND)
LRCL: U2.42 (LRCL), U4.2 (LRCL)
RX: U1.15 (RX), U2.3 (D1_RX)

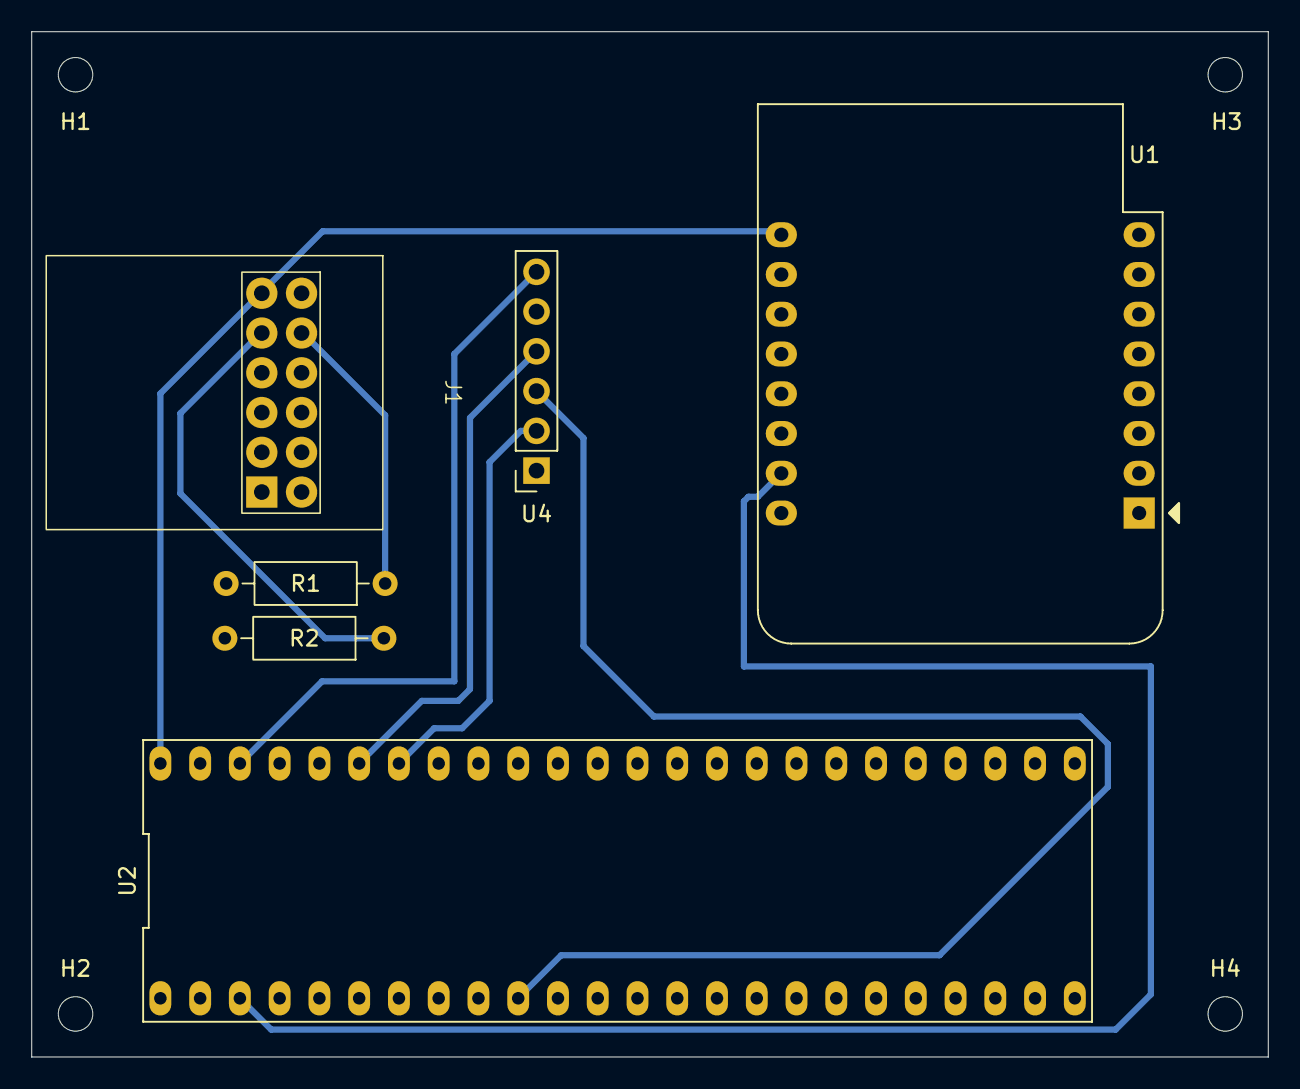
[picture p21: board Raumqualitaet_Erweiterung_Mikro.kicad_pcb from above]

Board: 2 copper layers, 79.0 x 65.5 mm, 10 parts (0 on the bottom side), 9 nets.

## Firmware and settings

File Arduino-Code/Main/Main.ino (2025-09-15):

//Allgemein
#include <Arduino.h>
#include <Wire.h>
#include <Adafruit_I2CDevice.h>

#include <ArduinoJson.h>
StaticJsonDocument<4096> daten;

JsonArray sensors;
JsonObject sensors_bme280;
JsonArray sensors_bme280_readings;
JsonObject sensors_bme_temp;
JsonObject sensors_bme_pres;
JsonObject sensors_bme_hum;
JsonObject sensors_ccs811;
JsonArray sensors_ccs811_readings;
JsonObject sensors_ccs_co2;
JsonObject sensors_ccs_tvoc;
JsonObject sensors_dust;
JsonArray sensors_dust_readings;
JsonObject sensors_dust_ratio;
JsonObject sensors_dust_conc;
JsonObject sensors_dust_lpo;
JsonObject sensors_mems;
JsonArray sensors_mems_readings;
JsonObject sensors_mems_val;
JsonObject sensors_mems_max;
JsonObject sensors_mhz19;
JsonArray sensors_mhz19_readings;
JsonObject sensors_mhz19_co2;
JsonObject sensors_mhz19_temp;
JsonObject sensors_sht35;
JsonArray sensors_sht35_readings;
JsonObject sensors_sht35_temp;
JsonObject sensors_sht35_hum;
JsonObject sensors_tcs;
JsonArray sensors_tcs_readings;
JsonObject sensors_tcs_lux;
JsonObject sensors_tcs_colortemp;
JsonObject sensors_tcs_clear;
JsonObject sensors_tcs_red;
JsonObject sensors_tcs_green;
JsonObject sensors_tcs_blue;
JsonObject sensors_typk1;
JsonArray sensors_typk1_readings;
JsonObject sensors_typk1_temp_hot;
JsonObject sensors_typk1_temp_cold;
JsonObject sensors_typk1_adc;
JsonObject sensors_typk2;
JsonArray sensors_typk2_readings;
JsonObject sensors_typk2_temp;
JsonObject sensors_uv;
JsonArray sensors_uv_readings;
JsonObject sensors_uv_uv;
char jsonBuffer[4096];

#define BAUDRATE 9600  //Terminal Baudrate

//Configuration
int ads_sensor = 0;
int mhz_sensor = 0;
int ccs_sensor = 0;
int bme_sensor = 0;
int tcs_sensor = 0;
int dust_sensor = 0;
int uv_sensor = 0;
int sht_sensor = 0;
int wifi_sensor = 0;
int typk_sensor = 0;
int typk_spi_sensor = 0;
int mic_sensor = 0;
int oled_sensor = 0;
String ssid = "";
String ARDUINO_ID = "";

//https://forum.arduino.cc/t/what-is-the-esp8266-wemos-d1-mini-max-voltage-in/640646/4

//int bt = A0;
int bt = 12;
int start = 0;
int druck = 0;
int wlanNummer = 0;

unsigned long lastMillis;

//WIFI
#include <ESP8266WiFi.h>
#include <ESP8266HTTPClient.h>
#define SERVER_IP "192.168.1.1"

String STASSID = "";
String STAPSK = "luftqualitaet";

WiFiClient client;

HTTPClient http;

int httpCode = 0;
//MHZ
#include <MHZ19.h>
#include <SoftwareSerial.h>
#define RX_PIN 0  //MH-Z19 RX-PIN
#define TX_PIN 2  //MH-Z19 TX-PIN

MHZ19 myMHZ19;
SoftwareSerial mySerial(RX_PIN, TX_PIN);

String mhz_temp = "";
String mhz_co2 = "";

//CCS811
String ccs_co2 = "";
String ccs_tvoc = ""; 

#include <CCS811-SOLDERED.h>
CCS_811 ccs811Sensor;

//BME280
#include <BME280I2C.h>

BME280I2C::Settings settings(
  BME280::OSR_X1,
  BME280::OSR_X1,
  BME280::OSR_X1,
  BME280::Mode_Forced,
  BME280::StandbyTime_1000ms,
  BME280::Filter_Off,
  BME280::SpiEnable_False,
  BME280I2C::I2CAddr_0x76  // I2C address. I2C specific.
  //BME280I2C::I2CAddr_0x77  // I2C address. I2C specific.
);
BME280I2C bme(settings);

//TCS
String tcs_lux = "";
String tcs_color_temp = ""; 
#include <Adafruit_TCS34725.h>
Adafruit_TCS34725 tcs = Adafruit_TCS34725(TCS34725_INTEGRATIONTIME_50MS, TCS34725_GAIN_1X);

//Dust
int Grove_Dust_DigitalPin = 14;
unsigned long Grove_Dust_lowpulseoccupancy = 0;
float Grove_Dust_ratio = 0;
float Grove_Dust_concentration = 0;
unsigned long sampletime_ms = 10000;
unsigned long duration;

//ads
#include <Adafruit_ADS1X15.h>
Adafruit_ADS1115 ads;
int16_t adc0, adc1, adc2, adc3;

//uv
int sensorValue;
long sum = 0;
int uv_val = 0;
String uv_out = "";

//SHT35
#include <ArtronShop_SHT3x.h>
ArtronShop_SHT3x sht3x(0x45, &Wire); // ADDR: 0 => 0x44, ADDR: 1 => 0x45


//Typk

#include <SPI.h>
#include <Adafruit_MAX31855.h>
#define MAXDO   16 //D0 = Miso
#define MAXCS   15 //D8 = SS
#define MAXCLK  13 //D7 = SCK
Adafruit_MAX31855 thermocouple(MAXCLK, MAXCS, MAXDO);

#include <Adafruit_I2CDevice.h>
#include <Adafruit_I2CRegister.h>
#include <Adafruit_MCP9600.h>
Adafruit_MCP9600 mcp;

Ambient_Resolution ambientRes = RES_ZERO_POINT_0625;


//Mic
float rms = 0;
float peak = 0;
int count = 0;
String data = "";

//OLED
#include <Adafruit_GFX.h>
#include <Adafruit_SH110X.h>
#define i2c_Address 0x3c

#define SCREEN_WIDTH 128 // OLED display width, in pixels
#define SCREEN_HEIGHT 64 // OLED display height, in pixels
#define OLED_RESET -1   //   QT-PY / XIAO
Adafruit_SH1106G display = Adafruit_SH1106G(SCREEN_WIDTH, SCREEN_HEIGHT, &Wire, OLED_RESET);

String zeile1 = "";
String zeile2 = "";
String zeile3 = "";
String zeile4 = "";

#include <EEPROM.h>
const int RESET_PIN = A0; 
// Schwellenwert für das "HIGH"-Signal. Ein Wert > 900 ist bei 1024-Bit-Auflösung ein guter Wert für HIGH.
const int RESET_THRESHOLD = 900; 
// Größe des EEPROM-Speichers in Bytes. 512 ist ein üblicher Wert.
const int EEPROM_SIZE = 512;

// Adresse im EEPROM für das Flag, das den ersten Start markiert.
const int firstStartFlagAddress = 0;
// Startadresse im EEPROM, an der die ID gespeichert wird.
const int idStorageAddress = 1;


void setup() {
  Serial.begin(BAUDRATE);
  mySerial.begin(BAUDRATE);  //Inialize

  Wire.begin();              //Inialize I2C Hardware
  EEPROM.begin(512);

  storage();

  configuration();

  if (oled_sensor){
    oled_INIT();
  }
  zeile1 = "SETUP Startet";
  zeile2 = "Bitte Warten";
  zeile4 = "okay";
  if (oled_sensor){
    oled_DATA();
  }
  if (ads_sensor){
    ads_INIT();
  }
  if (mhz_sensor){
    mhz_INIT();
  }
  if (ccs_sensor){
    ccs_INIT();
  }
  if (bme_sensor){
    bme_INIT();
  }
  if (tcs_sensor){
    tcs_INIT();
  }
  if (dust_sensor){
    dust_INIT();
  }
  if (sht_sensor){
    sht_INIT();
  }
  if (typk_sensor){
    typk_INIT();
  }
  if (typk_spi_sensor){
    typk_spi_INIT();
  }
  if (mic_sensor){
    mic_INIT();
  }
  start_INIT();

  if (wifi_sensor){
    wifi_INIT();
  }
  init_output();

  zeile1 = "LOOP Start";
  zeile2 = ARDUINO_ID;
  zeile4 = "okay";
  if (oled_sensor){
    oled_DATA();
  }
}

void loop() {
  zeile1 = "LOOP Laeuft";
  zeile2 = ARDUINO_ID;
  zeile4 = "okay";
  if (oled_sensor){
    oled_DATA();
  }
  
  if (dust_sensor){
    dust_collect_DATA();
  }

  if (mic_sensor){
    mic_collect_DATA();
  }
  
  //if (millis() - lastMillis >= 1*60*1000UL){
  if (millis() - lastMillis >= sampletime_ms) {
    lastMillis = millis();  //get ready for the next iteration

    Serial.println(ARDUINO_ID);
    Serial.println("--------------------------------------------------------------");
    generate_output();

    if (wifi_sensor){
      wifi_DATA();
    }
    
    if (mhz_sensor){
      mhz_DATA();
    }
    if (ccs_sensor){
      ccs_DATA();
    }
    if (bme_sensor){
      bme_DATA();
    }
    if (tcs_sensor){
      tcs_DATA();
    }
    if (dust_sensor){
      dust_DATA();
    }
    if (uv_sensor){
      uv_DATA();
    }
    if (sht_sensor){
      sht_DATA();
    }
    if (typk_sensor){
      typk_DATA();
    }
    if (typk_spi_sensor){
      typk_spi_DATA();
    }
    if (mic_sensor){
      mic_DATA();
    }

    Serial.println("--------------------------------------------------------------");
  }
  yield();
}

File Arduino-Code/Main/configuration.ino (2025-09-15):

int ID;
void configuration() {

  switch (ID) {
    case 0:
      ARDUINO_ID = "Arduino_0"; 
      
	  ads_sensor = 1;
      mhz_sensor = 1;
      ccs_sensor = 1;
      bme_sensor = 1;
      tcs_sensor = 1;
      dust_sensor = 1;
      uv_sensor = 1;
      sht_sensor = 1;
      typk_spi_sensor = 1; //SPI
      typk_sensor = 0;
      wifi_sensor = 1;
      oled_sensor = 1;
      mic_sensor = 0;
      break;
    case 1:
      ARDUINO_ID = "Arduino_1";
	  
	  ads_sensor = 1;
      mhz_sensor = 1;
      ccs_sensor = 1;
      bme_sensor = 1;
      tcs_sensor = 1;
      dust_sensor = 1;
      uv_sensor = 1;
      sht_sensor = 0;
      typk_spi_sensor = 0; //SPI
      typk_sensor = 1;
      wifi_sensor = 1;
      oled_sensor = 1;
      mic_sensor = 0;
      break; 

    case 2:
      ARDUINO_ID = "Arduino_2";

      ads_sensor = 1;
      mhz_sensor = 1;
      ccs_sensor = 1;
      bme_sensor = 1;
      tcs_sensor = 1;
      dust_sensor = 1;
      uv_sensor = 1;
      sht_sensor = 0;
      typk_spi_sensor = 0; //SPI
      typk_sensor = 1;
      wifi_sensor = 1;
      oled_sensor = 1;
      mic_sensor = 0;
      break;

    case 3:
      ARDUINO_ID = "Arduino_3";

      ads_sensor = 1;
      mhz_sensor = 1;
      ccs_sensor = 1;
      bme_sensor = 1;
      tcs_sensor = 1;
      dust_sensor = 1;
      uv_sensor = 1;
      sht_sensor = 1;
      typk_spi_sensor = 0; //SPI
      typk_sensor = 1;
      wifi_sensor = 1;
      oled_sensor = 1;
      mic_sensor = 0;
      break; 

    case 4:
      ARDUINO_ID = "Arduino_4";
      
      ads_sensor = 1;
      mhz_sensor = 1;
      ccs_sensor = 1;
      bme_sensor = 1;
      tcs_sensor = 1;
      dust_sensor = 1;
      uv_sensor = 1;
      sht_sensor = 0;
      typk_spi_sensor = 0; //SPI
      typk_sensor = 1;
      wifi_sensor = 1;
      oled_sensor = 1;
      mic_sensor = 0;
      break;

    case 5:
      ARDUINO_ID = "Arduino_5";
      
      ads_sensor = 1;
      mhz_sensor = 1;
      ccs_sensor = 1;
      bme_sensor = 1;
      tcs_sensor = 1;
      dust_sensor = 1;
      uv_sensor = 1;
      sht_sensor = 0;
      typk_spi_sensor = 0; //SPI
      typk_sensor = 1;
      wifi_sensor = 1;
      oled_sensor = 1;
      mic_sensor = 0;
      break;

    case 6:
      ARDUINO_ID = "Arduino_6";
      
      ads_sensor = 1;
      mhz_sensor = 1;
      ccs_sensor = 1;
      bme_sensor = 1;
      tcs_sensor = 1;
      dust_sensor = 1;
      uv_sensor = 1;
      sht_sensor = 0;
      typk_spi_sensor = 0; //SPI
      typk_sensor = 1;
      wifi_sensor = 1;
      oled_sensor = 1;
      mic_sensor = 0;
      break; 

    case 7:
      ARDUINO_ID = "Arduino_7";
      
  	  ads_sensor = 1;
      mhz_sensor = 1;
      ccs_sensor = 1;
      bme_sensor = 1;
      tcs_sensor = 1;
      dust_sensor = 1;
      uv_sensor = 1;
      sht_sensor = 0;
      typk_spi_sensor = 0; //SPI
      typk_sensor = 1;
      wifi_sensor = 1;
      oled_sensor = 1;
      mic_sensor = 0;
      break; 

    case 8:
      ARDUINO_ID = "Arduino_8";
      
      ads_sensor = 1;
      mhz_sensor = 1;
      ccs_sensor = 1;
      bme_sensor = 1;
      tcs_sensor = 1;
      dust_sensor = 1;
      uv_sensor = 1;
      sht_sensor = 0;
      typk_spi_sensor = 0; //SPI
      typk_sensor = 1;
      wifi_sensor = 1;
      oled_sensor = 1;
      mic_sensor = 0;
      break; 

    case 9:
      ARDUINO_ID = "Arduino_9";

      ads_sensor = 1;
      mhz_sensor = 1;
      ccs_sensor = 1;
      bme_sensor = 1;
      tcs_sensor = 1;
      dust_sensor = 1;
      uv_sensor = 1;
      sht_sensor = 0;
      typk_spi_sensor = 0; //SPI
      typk_sensor = 1;
      wifi_sensor = 1;
      oled_sensor = 1;
      mic_sensor = 0;
      break; 

    case 10:
      ARDUINO_ID = "Arduino_10";

      wifi_sensor = 1;
      mic_sensor = 1;
      ssid = "c24059";
      break;

    case 11:
      ARDUINO_ID = "Arduino_11";

      wifi_sensor = 1;
      mic_sensor = 1;
      ssid = "c24148";
      break;

    case 12:
      ARDUINO_ID = "Arduino_12";

      wifi_sensor = 1;
      mic_sensor = 1;
      ssid = "c24062";
      break;

    case 13:
      ARDUINO_ID = "Arduino_13";

      wifi_sensor = 1;
      mic_sensor = 1;
      ssid = "c24150";
      break;

    case 14:
      ARDUINO_ID = "Arduino_14";

      wifi_sensor = 1;
      mic_sensor = 1;
      ssid = "c24061";
      break;

    case 15:
      ARDUINO_ID = "Arduino_15";

      wifi_sensor = 1;
      mic_sensor = 1;
      ssid = "c24153";
      break;

    case 16:
      ARDUINO_ID = "Arduino_16";

      wifi_sensor = 1;
      mic_sensor = 1;
      ssid = "c25875";
      break;

    case 17:
      ARDUINO_ID = "Arduino_17";

      wifi_sensor = 1;
      mic_sensor = 1;
      ssid = "c25876";
      break;

    case 18:
      ARDUINO_ID = "Arduino_18";

      wifi_sensor = 1;
      mic_sensor = 1;
      ssid = "c25877";
      break;

    case 19:
      ARDUINO_ID = "Arduino_19";

      wifi_sensor = 1;
      mic_sensor = 1;
      ssid = "n23767";
      break;
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
